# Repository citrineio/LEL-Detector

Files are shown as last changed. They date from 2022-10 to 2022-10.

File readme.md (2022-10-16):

# Project Description

This project takes inspiration from my current job as a control and instrumentation engineer in the oil and gas industry. We have to deal with the risk of combustible or toxic gases leaks and one of the mandatory protection mechanisms is having a gas detection system. I designed a detector for combustible gases especially H2 which utilizes a common communication protocol to send data to the main controller in the system. 

This project incorporates the following: 
- SGP30 air quality sensor with H2 detection capability
- STM32F103 microcontroller
- LTC2631ITS8 I2C DAC with voltage output
- AD5749 4-20mA transmitter IC to send data to a connector and then to the control system.
- AOM12864A0 1.54" OLED display for reading the sensor's value.
- Two Omron relays for controlling and signaling an alarm light and a horn during a gas leak.

## Block Diagram

Block Diagram

## Board Images

LEL Detector Nice

LEL Detector

LEL Detector back

## Repository Guide:

### 3D:

3D model of the PCB, 3D models of the components are also available in the dedicated folder.

### PCB Layout: 

The latest Kicad PCB layout file is here. You can find component land patterns (aka footprints) in the dedicated folder.

### Schematics:

The latest Kicad schematics capture files are here. PDF version will be updated weekly during the schematics capture phase. You can also find the schematics symbols in the dedicated folder.

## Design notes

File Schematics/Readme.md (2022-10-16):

# Schematics

In this directory, you can find the up to date schematics files. The schematics were developed using kicad.

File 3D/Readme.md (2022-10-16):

# SBC 3D Model

Here, you can find the latest version of the board's 3D model as well as the parts.

Naming Format: 3D - SBC - V[x]

where x is the version.

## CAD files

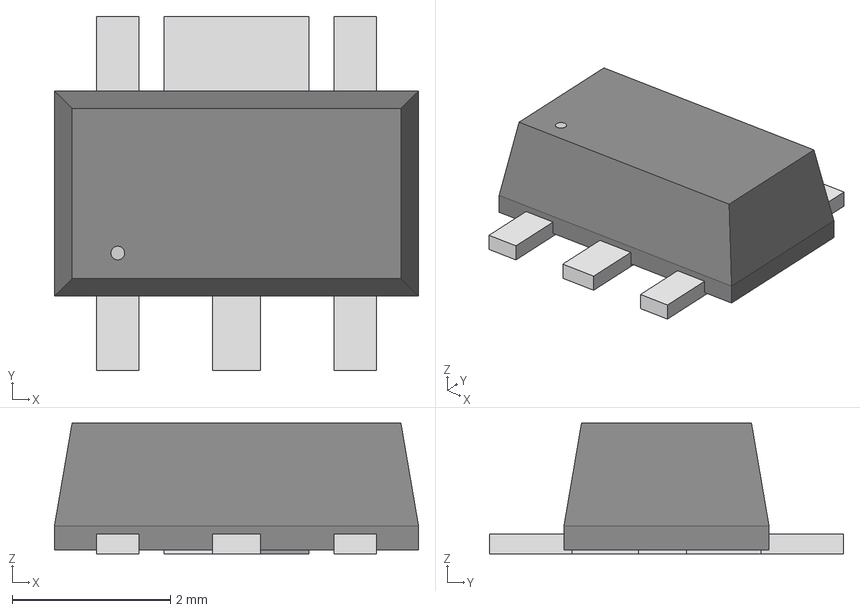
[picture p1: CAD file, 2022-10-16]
3D/3D Models/3D - AP7361C -3V3 LDO - V1.step
4.60 x 4.47 x 1.65 mm

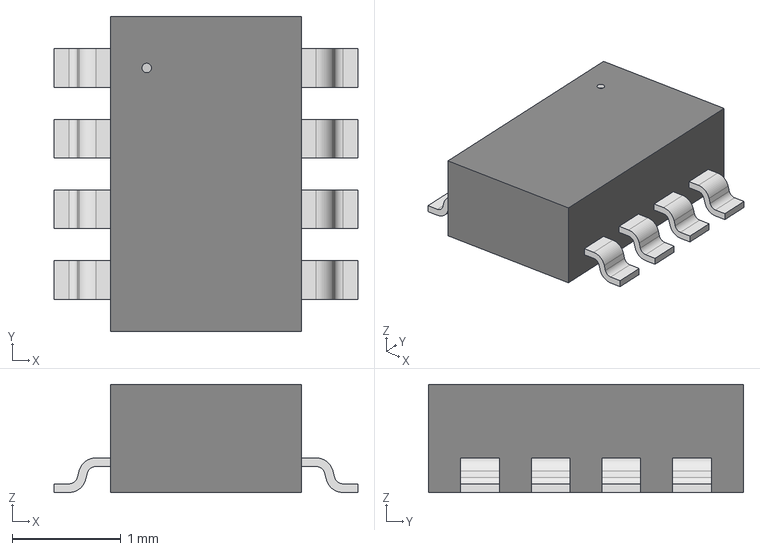
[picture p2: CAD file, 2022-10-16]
3D/3D Models/3D - LTC23631ITS8 - DAC.step
2.79 x 2.90 x 0.993 mm

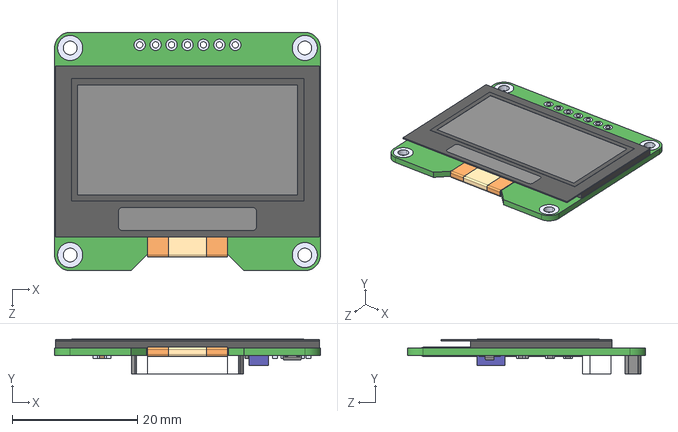
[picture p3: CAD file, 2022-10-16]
3D/3D Models/3D - AOM12864A0 - Display.step
42.4 x 5.50 x 38.0 mm

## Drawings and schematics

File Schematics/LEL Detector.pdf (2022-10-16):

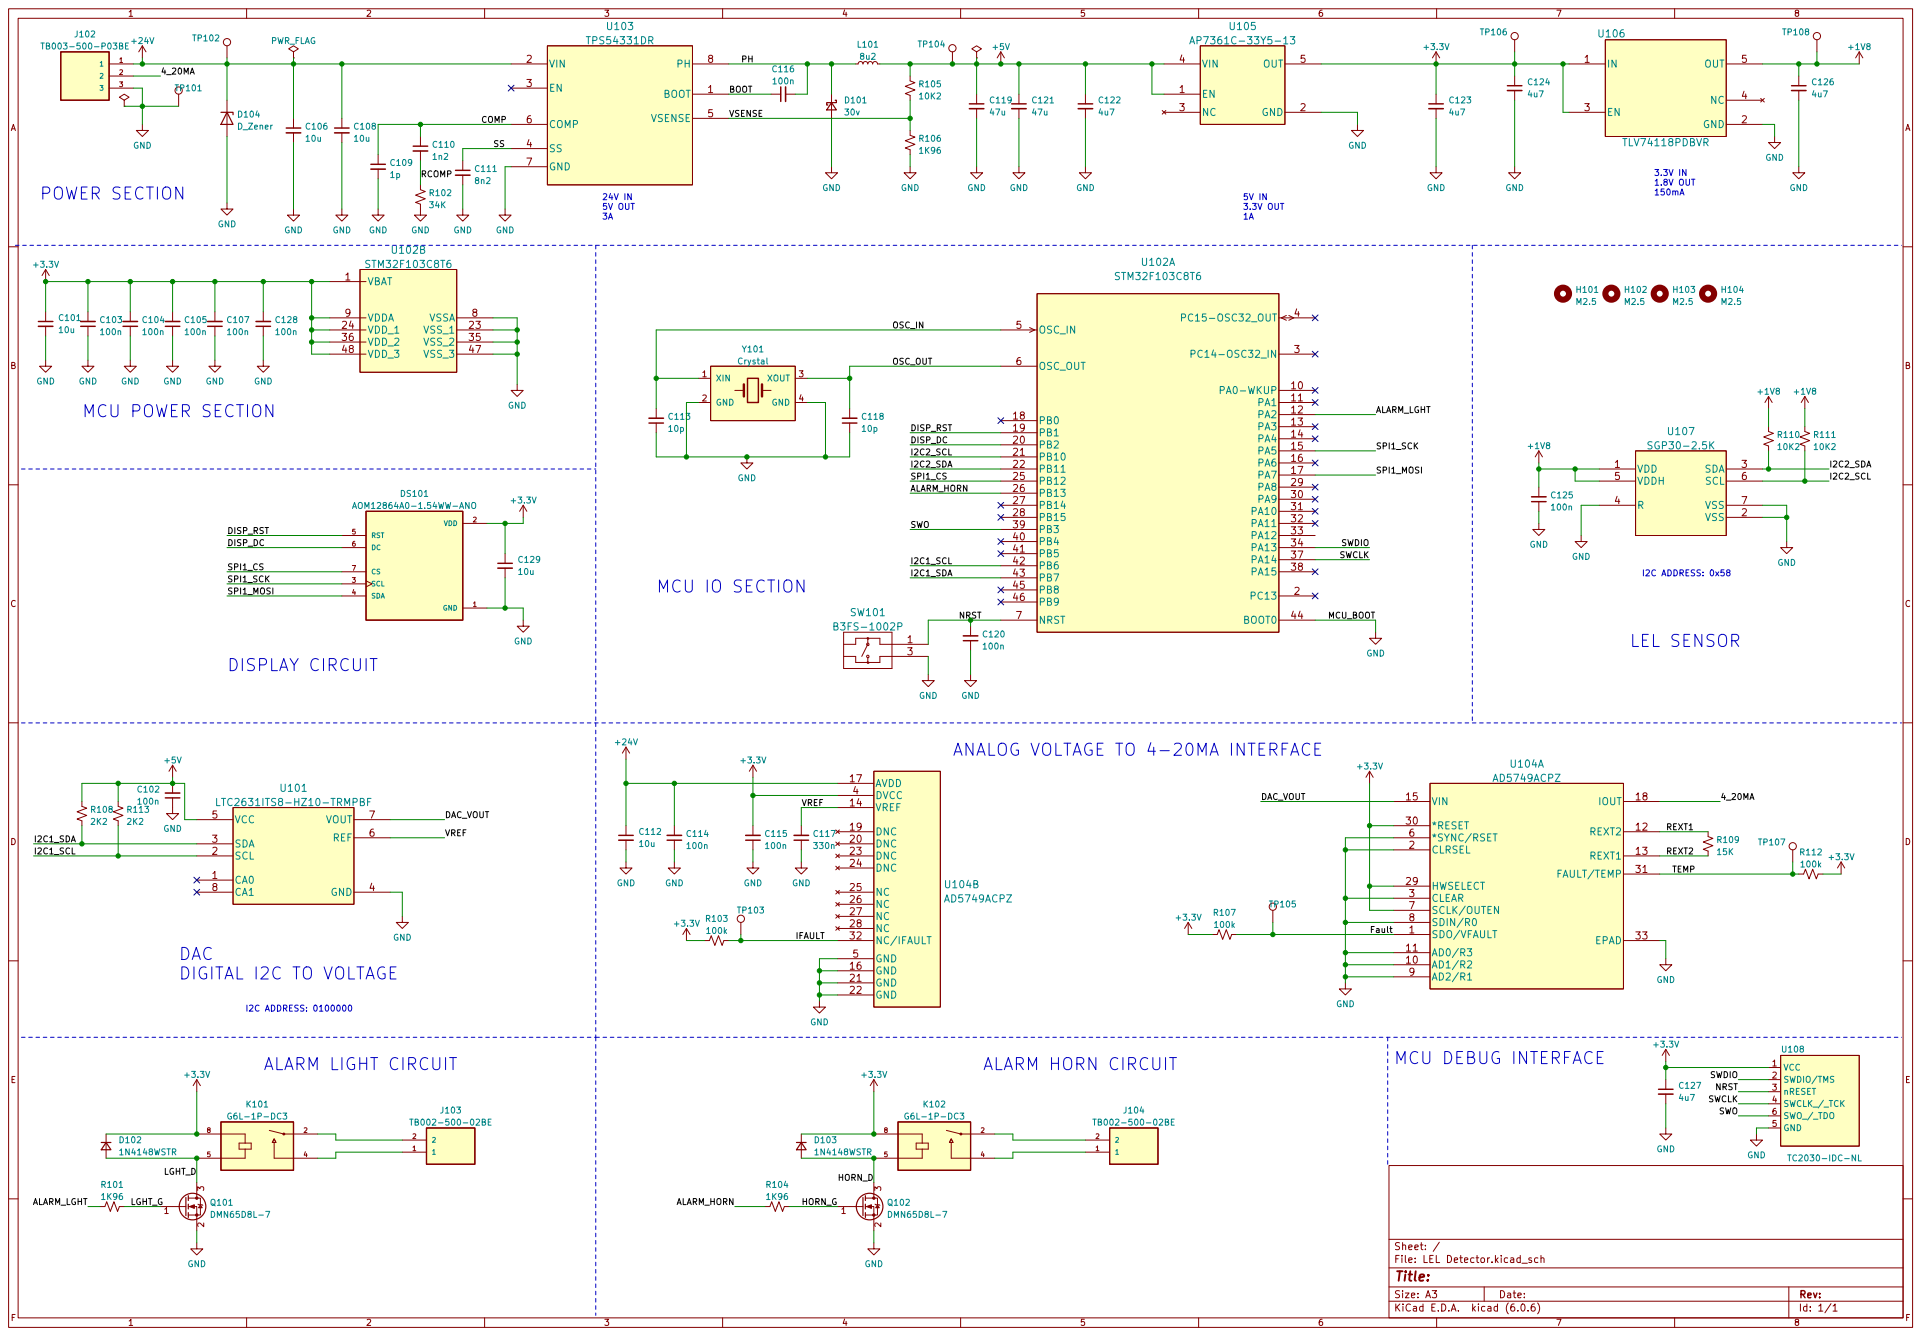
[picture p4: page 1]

I2C ADDRESS: 0x58 PAUSED TEMPORARILY, DAC WAS NOT COMPATIBLE, NEED TO SWITCH TO

ANALOG VOLTAGE TO 4-20MA INTERFACE

2 3 Q102 DMN65D8L-7 CA0 1 SCL 2 SDA 3 GND 4 VCC 5 REF 6 VOUT 7 CA1 8 U101
LTC2631ITS8-HZ10-TRMPBF

File: LEL Detector.kicad_sch Sheet: / GND

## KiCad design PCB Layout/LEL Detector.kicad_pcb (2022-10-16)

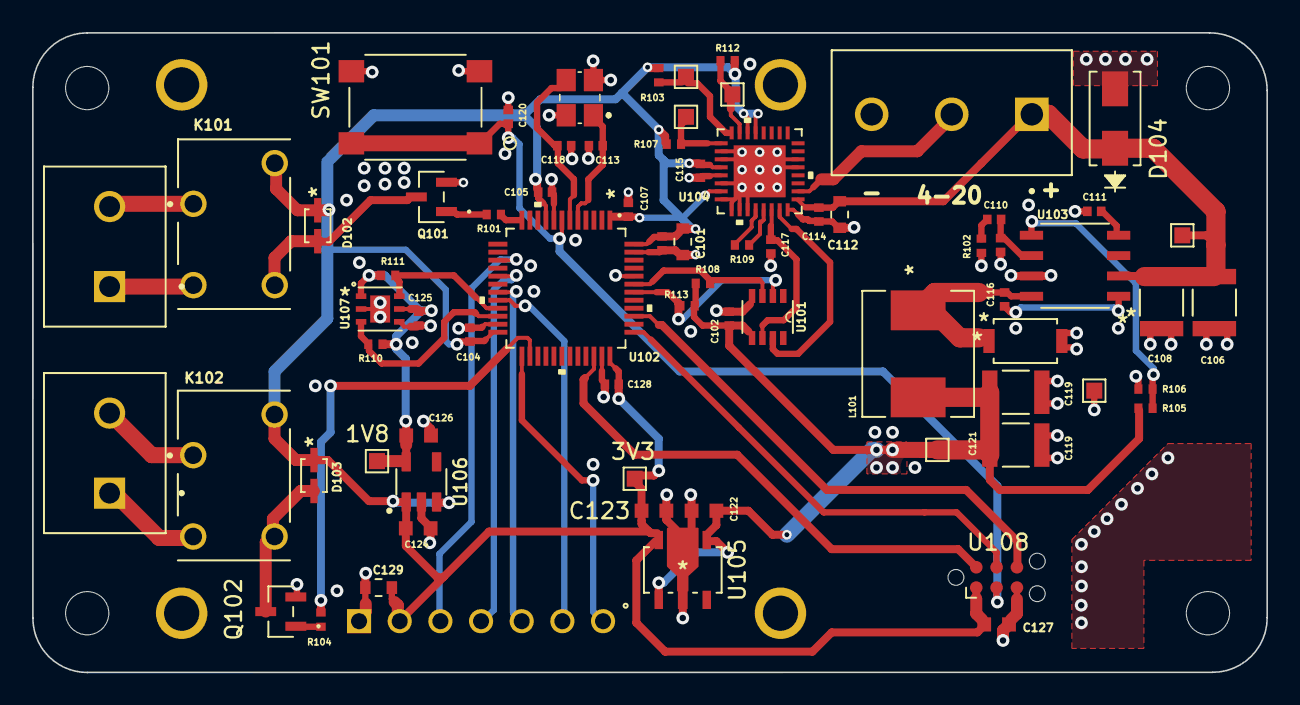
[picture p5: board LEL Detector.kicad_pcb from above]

Board: 4 copper layers, 77.1 x 39.9 mm, 77 parts (1 on the bottom side), 44 nets.

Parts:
1V8, 3V3, 5V101, 24V101: TestPoint; TestPoint_Pad_1.0x1.0mm
C101, C112, C129: 10u; SAMSUNG_10u_0603
C102, C103, C104, C105, C107, C114, C115, C116, C120, C125, C128: 100n; CAPC1005X55N_1n2
C106, C108: 10u; CAPC3225X270N_10U
C109: 1p; CAPC1005X55N_1n2
C110: 1n2; CAPC1005X55N_1n2
C111: 8n2; CAPC1005X55N_1n2
C113, C118: 10p; CAPC1005X55N_1n2
C117: 330n; CAPC1005X55N_330n
C119, C121: 47u; CAPC3225X270N_10U
C122, C123, C124, C126, C127: 4u7; MURATA_4u7_0603
D101: 30v; RB080LAM-30TR
D102, D103: SOD-323_SDS; 1N4148WSTR
D104: D_Zener; SMAJ40A-13-F_TVS
DS101: AOM12864A0-1.54WW-ANO; AOM12864A0-1.54WW-ANO_DISPLAY
GND101: TestPoint; TestPoint_Pad_1.0x1.0mm
H101, H102, H103, H104: M2.5; MountingHole_2.7mm_M2.5
IFAULT101: TestPoint; TestPoint_Pad_1.0x1.0mm
J102: TB003-500-P03BE; CUI_TB003-500-P03BE
J103, J104: TB002-500-02BE; CUI_TB002-500-02BE
K101, K102: G6L-1P-DC3; RELAY_G6L-1P-DC3
L101: 8u2; IHLP2525CZER8R2M01
Q101, Q102: DMN65D8L-7; DMN65D8L-7_MOSFET
R101, R104, R106: 1K96; RESC1005X40N
R102: 34K; RESC1005X40N
R103, R107, R112: 100k; RESC1005X40N
R105, R110, R111: 10K2; RESC1005X40N
R108, R113: 2K2; RESC1005X40N_2K2
R109: 15K; RESC1005X40N
SW101: B3FS-1002P; B3FS-1002P_BUTTON
TEMP101: TestPoint; TestPoint_Pad_1.0x1.0mm
U101: SOT-8_TS_LIT; LTC2631ITS8-HZ10-TRMPBF
U102: LQFP48-7x7mm; STM32F103C8T6
U103: D8; TPS54331DR
U104: CP_32_2_ADI; AD5749ACPZ
U105: SOT89-5_DIO; AP7361C-33Y5-13
U106: TLV74118PDBVR; SOT95P280X145-5N_1V8
U107: SGP30-2.5K_SEN; SGP30-2.5K
U108: TC2030-IDC-NL; Tag-Connect_TC2030-IDC-NL_2x03_P1.27mm_Vertical
VFAULT101: TestPoint; TestPoint_Pad_1.0x1.0mm
Y101: Crystal; ABM8G16000MHZB4YT

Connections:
+1V8: 1V8.1, C125.2, C126.1, R110.1, R111.1, U106.5 (OUT), U107.1 (VDD), U107.5 (VDDH)
+3.3V: 3V3.1, C101.1, C103.2, C104.2, C105.2, C107.2, C115.2, C123.1, C124.1, C127.1, C128.2, C129.1, D102.1 (K), D103.1 (K), DS101.2 (VDD), K101.8, K102.8, R103.1, R107.1, R112.1, U102.1 (VBAT), U102.9 (VDDA), U102.24 (VDD_1), U102.36 (VDD_2), U102.48 (VDD_3), U104.4 (DVCC), U104.7 (SCLK/OUTEN), U104.29 (HWSELECT), U104.30 (*RESET), U105.5 (OUT), U106.1 (IN), U106.3 (EN), U108.1 (VCC)
+5V: 5V101.1, C102.2, C119.1, C121.1, C122.1, L101.2, R105.1, R108.1, R113.1, U101.5 (VCC), U105.1 (EN), U105.4 (VIN)
+24V: 24V101.1, C106.1, C108.1, C112.1, C114.2, D104.1 (K), J102.1, U103.2 (VIN), U104.17 (AVDD)
/4_20MA: J102.2, U104.18 (IOUT)
/ALARM_HORN: R104.1, U102.26 (PB13)
/ALARM_LGHT: R101.1, U102.12 (PA2)
/BOOT: C116.1, U103.1 (BOOT)
/COMP: C109.1, C110.1, U103.6 (COMP)
/DAC_VOUT: U101.7 (VOUT), U104.15 (VIN)
/DISP_DC: DS101.6 (DC), U102.20 (PB2)
/DISP_RST: DS101.5 (RST), U102.19 (PB1)
/Fault: R107.2, U104.1 (SDO/VFAULT), VFAULT101.1
/HORN_D: D103.2 (A), K102.5, Q102.3 (D)
/HORN_G: Q102.1 (G), R104.2
/I2C1_SCL: R113.2, U101.2 (SCL), U102.42 (PB6)
/I2C1_SDA: R108.2, U101.3 (SDA), U102.43 (PB7)
/I2C2_SCL: R111.2, U102.21 (PB10), U107.6 (SCL)
/I2C2_SDA: R110.2, U102.22 (PB11), U107.3 (SDA)
/IFAULT: IFAULT101.1, R103.2, U104.32 (NC/IFAULT)
/LGHT_D: D102.2 (A), K101.5, Q101.3 (D)
/LGHT_G: Q101.1 (G), R101.2
/NRST: C120.2, SW101.1, SW101.2, U102.7 (NRST), U108.3 (nRESET)
/OSC_IN: C113.2, U102.5 (OSC_IN), Y101.1 (XIN)
/OSC_OUT: C118.2, U102.6 (OSC_OUT), Y101.3 (XOUT)
/PH: C116.2, D101.1 (K), L101.1, U103.8 (PH)
/RCOMP: C110.2, R102.1
/REXT1: R109.1, U104.12 (REXT2)
/REXT2: R109.2, U104.13 (REXT1)
/SPI1_CS: DS101.7 (CS), U102.25 (PB12)
/SPI1_MOSI: DS101.4 (SDA), U102.17 (PA7)
/SPI1_SCK: DS101.3 (SCL), U102.15 (PA5)
/SS: C111.1, U103.4 (SS)
/SWCLK: U102.37 (PA14), U108.4 (SWCLK_/_TCK)
/SWDIO: U102.34 (PA13), U108.2 (SWDIO/TMS)
/SWO: U102.39 (PB3), U108.6 (SWO_/_TDO)
/TEMP: R112.2, TEMP101.1, U104.31 (FAULT/TEMP)
/VREF: C117.2, U101.6 (REF), U104.14 (VREF)
/VSENSE: R105.2, R106.1, U103.5 (VSENSE)
GND: C101.2, C102.1, C103.1, C104.1, C105.1, C106.2, C107.1, C108.2, C109.2, C111.2, C112.2, C113.1, C114.1, C115.1, C117.1, C118.1, C119.2, C120.1, C121.2, C122.2, C123.2, C124.2, C125.1, C126.2, C127.2, C128.1, C129.2, D101.2 (A), D104.2 (A), DS101.1 (GND), GND101.1, J102.3, Q101.2 (S), Q102.2 (S), R102.2, R106.2, SW101.3, SW101.4, U101.4 (GND), U102.8 (VSSA), U102.23 (VSS_1), U102.35 (VSS_2), U102.44 (BOOT0), U102.47 (VSS_3), U103.7 (GND), U104.2 (CLRSEL), U104.3 (CLEAR), U104.5 (GND), U104.6 (*SYNC/RSET), U104.8 (SDIN/R0), U104.9 (AD2/R1), U104.10 (AD1/R2), U104.11 (AD0/R3), U104.16 (GND), U104.21 (GND), U104.22 (GND), U104.33 (EPAD), U105.2 (GND), U106.2 (GND), U107.2 (VSS), U107.4 (R), U107.7 (VSS), U108.5 (GND), Y101.2 (GND), Y101.4 (GND)
unnamed: J103.1, K101.4
unnamed: J103.2, K101.2
unnamed: J104.1, K102.4
unnamed: J104.2, K102.2

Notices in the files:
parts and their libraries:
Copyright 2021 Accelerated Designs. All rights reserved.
